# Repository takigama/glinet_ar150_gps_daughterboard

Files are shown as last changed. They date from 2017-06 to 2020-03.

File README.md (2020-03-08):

## Update - 2020, Mar 9

I've been running my little guys for 3 years now. I have two in outdoor cases
being powered over ethernet and they have yet to skip a beat, which is suprising.
As some of you may know, Australia (especially NSW) has been going through
some hard times this summer. First it was an amazing heatwave followed by fire
Then it was floods and intense rain. They endured both. Going up against two
RPI's (both RPI's died in the heat), thats doing pretty well.

I've now added a 2020 firmware release which is based on 19.07.2. This time
i've included all the packages as well and made as many modules as would
compile. If you do need any extra modules, they should now already be available

I've not chaned the firmware to point here for packages however, so you need
to grab them manually.

I also plan on publishing a build guide for the external cases, hopefully
some time soon.

## What be it?

Simple daughter board for the AR150 from GL.inet using the Quectel L80 GPS or
the MTK3339 GPS (there are boards for either)

... and its AWESOME!!!!

... and NOW with added linuxptp AND LEDE support!!!!!

note that it doesnt come configured with much, so most of the daemons included
(ntp, chrony, etc) start up automatically with defaults, you want to change
that

## Why?

meh, why not?

Seriously though, some time ago I used the predessesor of the AR150 and the
uBlox Neo 6m GPS receiver to build a NTP with GPS and PPS for high accuracy
timing. [See here](http://pjrlost.blogspot.com.au/2015/09/ar9331-pps-gps-ntp-awesome.html)
I had to write some code to enable PPS interupt based processing on the AR9331
family (thanks to some code that already supported GPIO's with interrupts)
and was fairly impressed with the results. At home its the prefered clock
source, going up against a RPI1, RPI2 and a Wyse terminal with a serial port
which runs an AMD geode cpu.

Sadly its hard to get the Neo uBlox 6M in an SMD format, but I stumbled onto
the Quectel L80 chip, which is easy to aquire and even smaller than the uBlox. The AR150
has different GPIO pins to the original GL.inet router I had in my previous
project (which is still actually running at home and still out-performing
most other GPS/PPS's i've built).

A number of projects do use the AR9331 as a GPS/PPS/NTP clock, but this was
the first one that I know of that implemented by the gpio interrupt mechanism
(which is more accurate and more efficient).

## How?

Well, first go print a board at oshpark [here](https://oshpark.com/shared_projects/Jt3Wxv2q)
and then go get a Quectel L80 chip (just the chip, no board), a couple of leds
a small mosfet (dont really need it to be honest) and a few resistors and lastly
of course a AR150.

Solder it all together, then sit back and wait for me to port my code on the
blog to the AR150 (only have to change the PPS pin from 13 to 14), or compile
the code yourself and figure that bit out.

Also, when i started this, i was thinking along the lines of the PoE version
of the AR150 (so the AR150 can sit outside in a silicon case with the GPS poking
upward thru the top - i'll post pic's when I build it)

Dont let the SMD scare you, plenty of youtubes up for how to hand solder or heat
gun solder this thing. I use a head gun for everything except the GPS module. I
use a soldering iron for the GPS module.

## BOM

1) 1 x L80 GPS Module or MTK3339 Module
2) 1 x Mosfet (BSS138 or similar) - optional, allows GPS to be power cycled by board
3) 3 x 200ohm 0805 SMD resistors
4) 1 x 2x5 90 degree angled pin header
5) 3 x 0805 leds (colour is up to you)

## GPIO's

So in the project, its using two GPIO's. One is used to turn the GPS itself on
and off. The other is used for the PPS interrupt. GPIO 17 is the power switch
GPIO 14 will be the PPS pin.

## Updates

3/Mar/2018 - There are now two firmwares sitting in the firmware directory. This
update moves my repo from its very-alpha state to something I now consider to be
relatively tested and working fairly stable and as such is now considered beta!

The baords have both beeen tested with fairly good success so far. I would
slightly recommend the L80 GPS over the MTK3339 GPS module as it seems more
sensative and less jittery.

Heres some Pics for you:

L80:
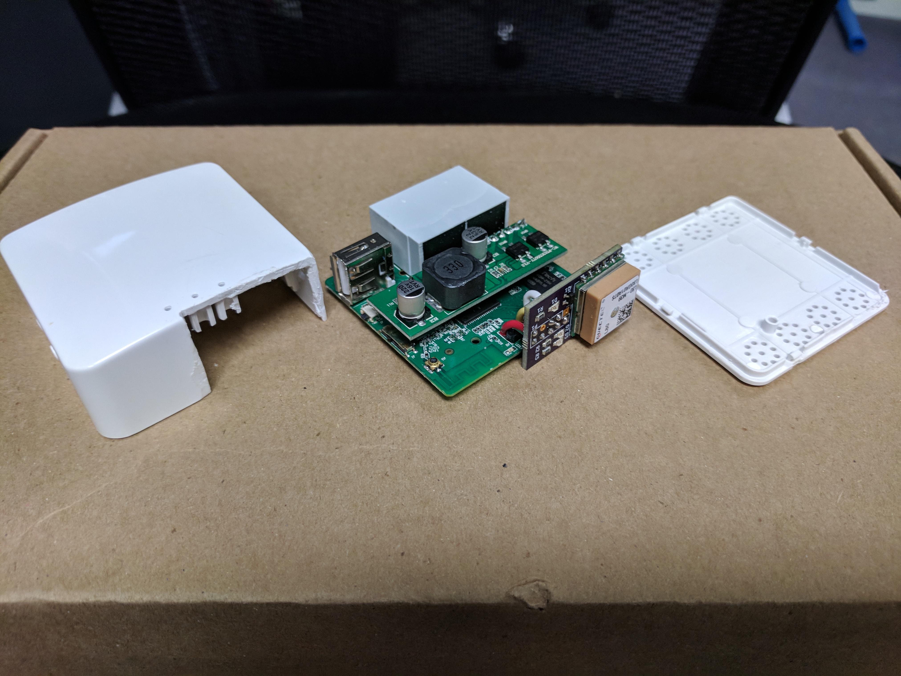
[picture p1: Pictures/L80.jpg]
L80


MTK3339:
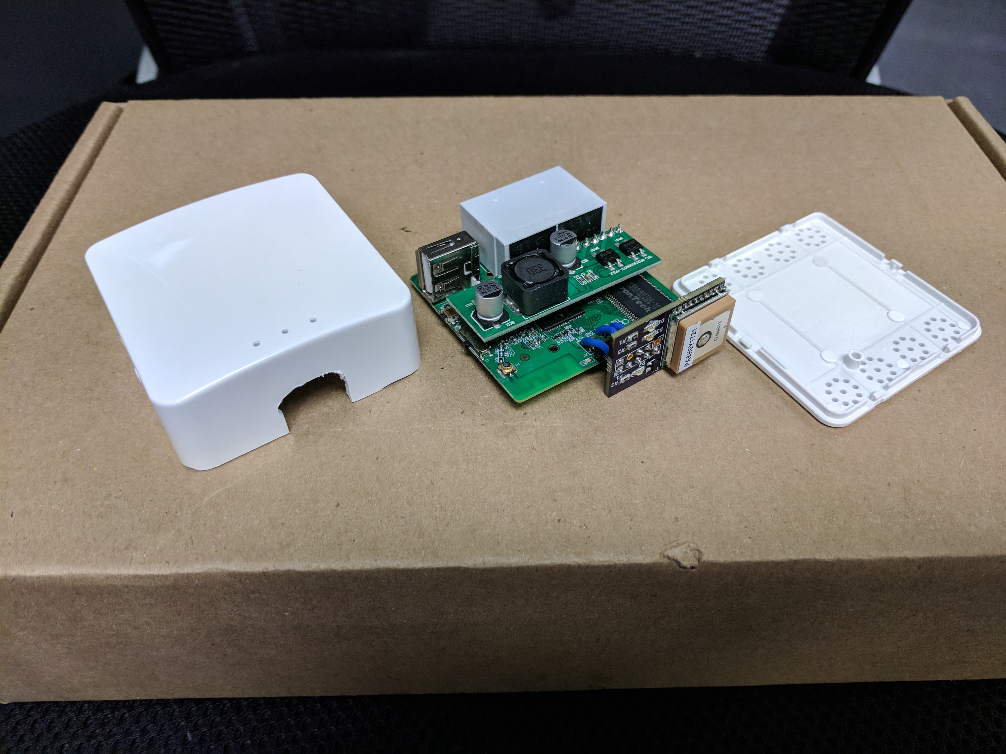
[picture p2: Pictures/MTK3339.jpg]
MTK3339


Theres no alot to distinguish between the two except they have different footprints
on the GPS module

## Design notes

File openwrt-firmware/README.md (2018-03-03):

# New firmwares - 3/Mar/2018

This new firmware is now pretty solid and there are two versions

1. LEDE based (based on lede github master)
2. openwrt based (comes from openwrt's own master git)

## Details

There are quite alof ot packages added, which i'll update shortly
but to install it, upload it to your AR150 (preferably already 
running openwrt) then run from the shell "sysupgrade -v /tmp/my_firmware_file"

Once you've done that, its a good idea to blank it when it comes up
by running "mtd -r erase rootfs_data" (this will reset the router
back to the golden image and reboot it).

On boot it will do a number of things:

1. set WAN interface to DHCP client
2. set wifi SSID to "OpenWRT" and give the wifi a 192.168.254.1 with dhcp server
3. set LAN interface to 192.168.253.1 with a dhcp server
4. enabble gpsd and chrony with two ntp servers on "noselect"
5. disables firewall!!!!
6. disables most every other service
7. disables the serial console

The reason we do all that is to remove as much cpu-consuming tasks from
the router as possible, but it is obviously insecure. If you dont need it
disable the wifi, but I would leave the firewall off, configure a static
IP and shutdown the web interface, and the "LAN" interface. On the PoE
model, the WAN interface is the one that accepts PoE and if your using 
the 3d printed outdoor case (coming soon(tm)), you'll only want a single
ethernet cable coming into the router.

Once its online and you can connect to it (either by plugging LAN into
your network, connecting to the SSID or connecting to the LAN interface)
ssh in and run "chronyc sources", it should start syncing. You can also
make sure gpsd is running correctly with cgps (you should see a 9600 baud
rate on the serial line)

One problem - for some reason after a sysupgrade or mtd erase step the wifi
does not come back online unless the router is rebooted again. So after
upgrading and resetting, make sure you reboot if you need wireless!

I'll make the firmwares available soon on githuba

If your not sure which firmware you installed, have a look in /etc/taki
and there will be a 0 byte file that it is either "lede" or "operwrt".

## PTP

This version has full ptp support, and starts the ptp daemon on startup
with the following parameters:

1. Software clock
2. Binds to eth0 and eth1
3. E2E delay
4. Pri1 and 2 at 128
5. Domain ID 0

## NTPD instead of Chrony.

My firmware defaults to starting up chrony. If you wish to use ntpd instead
just disable the chrony startup and enable the ntp one. Then configure
the ntpd.

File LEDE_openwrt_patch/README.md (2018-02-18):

# LEDE Patch for AR150 support

quick and nasty:

1. this is a hack
2. this IS a hack
3. hard codes the pps-gpio module to the GL-AR150
4. includes the configuration for building lede
5. follow https://openwrt.org/docs/guide-developer/quickstart-build-images for building lede
6. copy the lede patch 940-lede-patch-for-ar150-pps-gpio.patch to target/linux/ar71xx/patches-4.9/

Build it all!

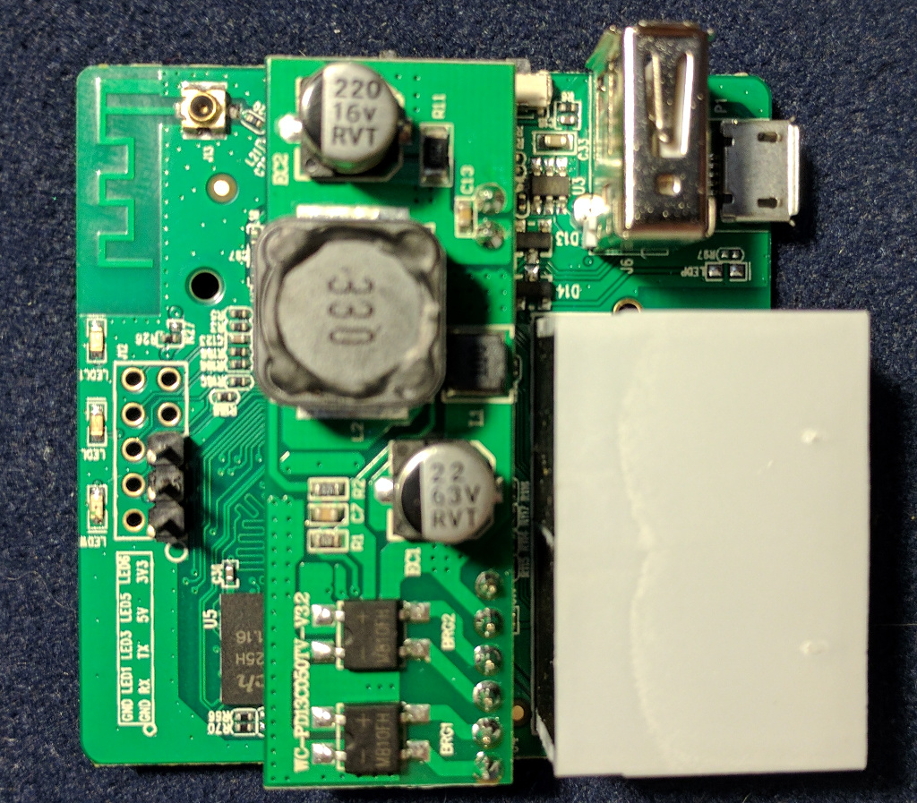
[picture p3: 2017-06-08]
GL150_pinout_change/IMG_20170608_214517_ws.jpg

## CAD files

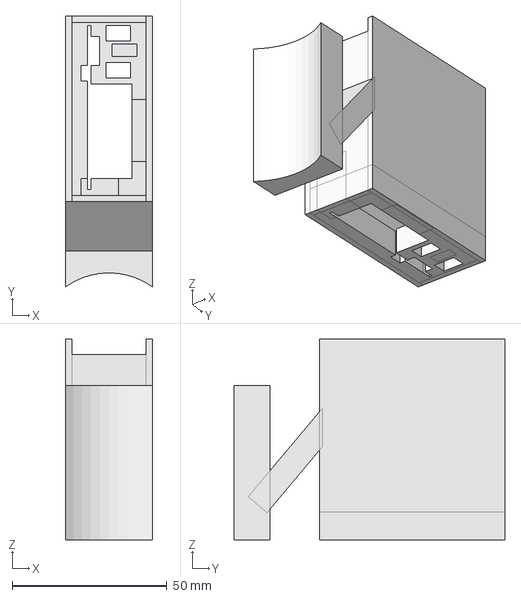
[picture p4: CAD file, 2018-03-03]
3D Printed Outdoor Case/maincase.fcstd
28.0 x 87.5 x 65.0 mm

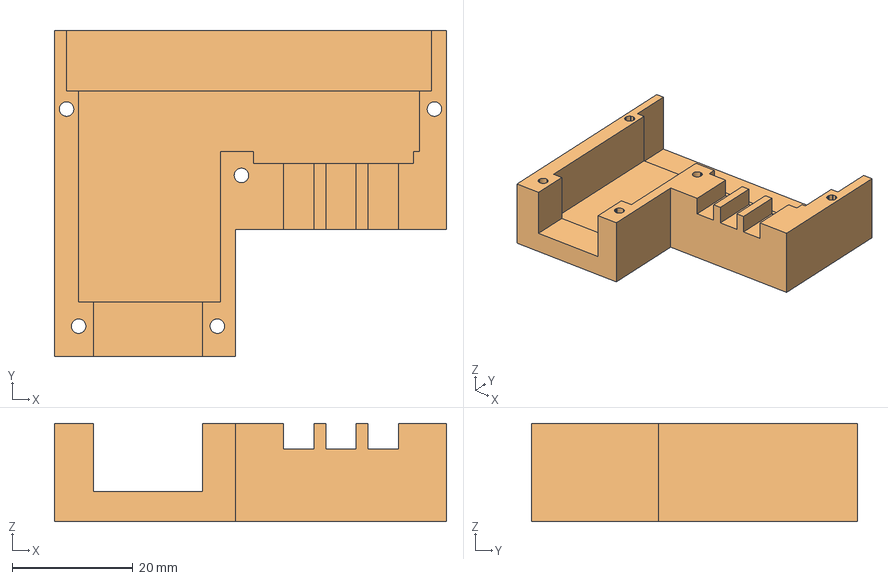
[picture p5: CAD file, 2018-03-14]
3D Printed Outdoor Case/cablein.fcstd
65.0 x 54.0 x 16.2 mm
Cut (Meshed)

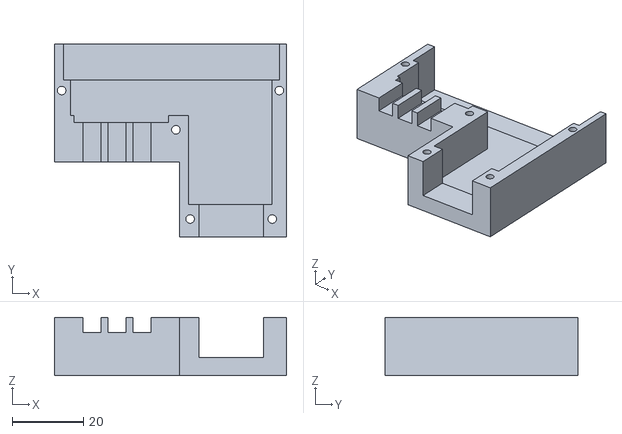
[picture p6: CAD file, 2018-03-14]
3D Printed Outdoor Case/cablein (mirrored).stl
65.0 x 54.0 x 16.2

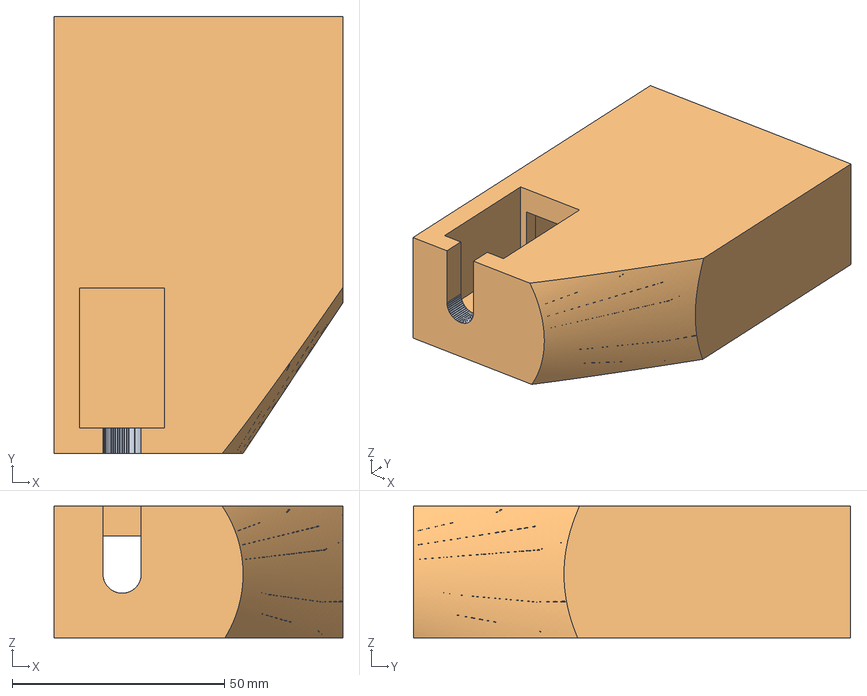
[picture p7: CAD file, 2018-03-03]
3D Printed Outdoor Case/ntpcase.fcstd
68.0 x 103.0 x 31.0 mm
Cut002 (Meshed)

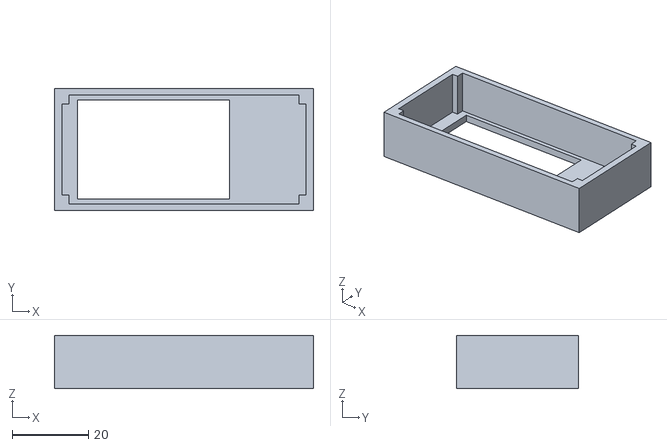
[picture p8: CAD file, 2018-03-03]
3D Printed Outdoor Case/captotp.stl
68.0 x 32.0 x 14.0

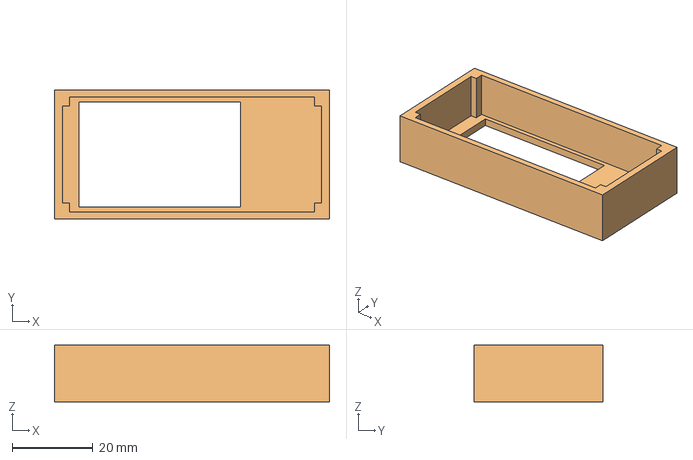
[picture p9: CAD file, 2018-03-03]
3D Printed Outdoor Case/cap_top.fcstd
68.0 x 32.0 x 14.0 mm
Cut (Meshed)

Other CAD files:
3D Printed Outdoor Case/cablein.stl
3D Printed Outdoor Case/maincase.stl
3D Printed Outdoor Case/ntpcase.stl

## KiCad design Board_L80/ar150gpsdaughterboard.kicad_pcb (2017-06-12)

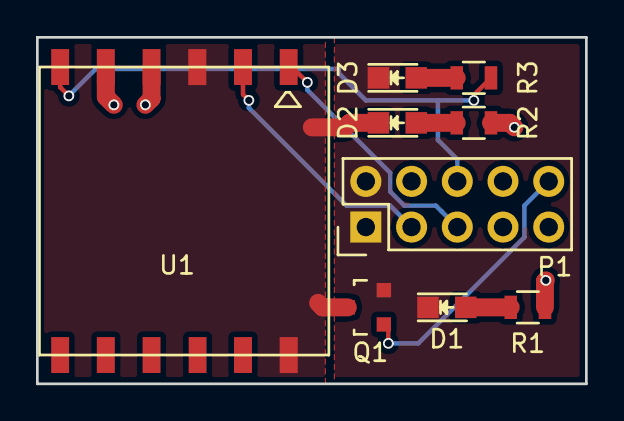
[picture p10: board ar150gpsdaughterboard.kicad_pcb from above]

Board: 2 copper layers, 30.5 x 19.2 mm, 9 parts (0 on the bottom side), 10 nets.

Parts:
D1, D2, D3: LED; LED_0805
P1: CONN_02X05; Pin_Header_Straight_2x05
Q1: BSS138; SOT-23
R1, R2, R3: 300; R_0805
U1: QUECTEL-L80

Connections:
+3V3: P1.9, R1.1, R2.1, U1.4, U1.5
GND: D1.1, D3.1, P1.1, P1.2, Q1.2
GP_14: P1.6, R3.1, U1.6
GP_17: P1.10, Q1.1
GP_GND: D2.1, Q1.3, U1.3, U1.12
unnamed: D1.2, R1.2
unnamed: D2.2, R2.2
unnamed: D3.2, R3.2
RX: P1.3, U1.2
TX: P1.5, U1.1

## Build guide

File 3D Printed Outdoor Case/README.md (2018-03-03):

# 3d Printed Outdoor Case

Its kind of a work in progress

How it comes together:

1. print maincase, cablein (and mirrored) and top
2. get a peice of silicon for the top
3. in cablein, theres a place to glue in a piece of mesh
4. rap some silicon around the cable going into cable in for water-proofedness
5. waterproof the rest
6. glue it together (cablein has holes for 1.75m filimant to hold it together).
7. .....
8. PROFIT!!!

if you cant figure it out from that, then you can try but when i complete this work
i'll give some instructions with photos and a better explanation.

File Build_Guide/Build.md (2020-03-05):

# Quick Run Through

## And then there was light

1. git clone https://git.openwrt.org/openwrt/openwrt.git
2. cd openwrt
3. git checkout v19.07.2
4. ./scripts/feeds update -a
5. ./scripts/feeds install -a
6. copy config.built to ./.config
7. copy 940-lede-patch-for-ar150-pps-gpio.patch to target/linux/ar71xx/patches-4.14/
8. make menuconfig (adjust as you need)
9. make
10. Cross fingers
11. firmware should now be in bin/targets/ar71xx/generic/

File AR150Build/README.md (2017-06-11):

## Details for building openwrt for this project...

The quick and dirty:
git clone https://github.com/openwrt/openwrt.git
git checkout d95f4c6ca377edcdf8c827a50b5e67e12313f9f6
git reset --hard # just incase

copy the 971 patch in this dir to target/linux/ar71xx/patches-4.1/ in your openwrt directory
copy the config in this directory to the root of your openwrt directory

Hope that it all builds. Theres one file that isnt downloaded during the build called
DPO_MT7601U_LinuxSTA_3.0.0.4_20130913.tar.bz2 which can be found via google. Download
that and it goes into your openwrt under a directory called dl/

upgrade your ar150 with the firmware you finially get out of it.

Or just upload the firmware in the openwrt-firmware directory.

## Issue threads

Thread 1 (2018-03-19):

Mounting ext4 USB

andersen73, 2018-03-19:
Loving the PPS on my AR150! Sadly, I'm not able to mount any USB drive (vfat, ext4, ntfs, etc...). Is there a reason why I'm not able to mount any USB flash drives? Are you seeing the same thing on your end? I need to be able to capture tcpdump .caps locally. Any help is appreciated. If you need any information from my end, please let me know. Thanks

takigama, 2018-07-02:
Probably my firmware (sorry just noticed the issue, must of missed the email), i'll compile a new one with the needed options added.

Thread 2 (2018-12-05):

Some Qs

Strykar, 2018-12-05:
1. What are your thoughts on using this [Uputronics breakout GPS board](https://store.uputronics.com/index.php?route=product/product&path=60_64&product_id=84) with the AR-150? I have an [external antenna](https://store.uputronics.com/index.php?route=product/product&path=60_65&product_id=74).
2. Why install PTP on the AR-150, iirc the AR9331 SoC NIC's don't support hardware time-stamping?
3. Have you tried https://github.com/mlichvar/pps-gpio-poll with your daughterboard? _Unlike the pps-gpio module (which is included in the Linux tree) it doesn’t use interrupts. It uses a high-resolution timer and waits for the GPIO value to change in a busy loop instead._
4. Could you post some performance numbers of the Quectel and MTK GPS?

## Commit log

2017-05-10 GL.inet AR150 GPS Daughter board Project
    [_saved_ar150gpsdaughterboard.sch, ar150gpsdaughterboard.dsn, ar150gpsdaughterboard.kicad_pcb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]
2017-06-08 new pinout
    [_saved_ar150gpsdaughterboard.sch, ar150gpsdaughterboard.sch]
2017-06-08 Updated board layout - new L80 footprint, better location of pins
    [ar150gpsdaughterboard.kicad_pcb]
2017-06-08 updated oshpark link in readme
    [ar150gpsdaughterboard.kicad_pcb]
2017-06-09 updated pinout of the ar150 pin header
    [ar150gpsdaughterboard.kicad_pcb, ar150gpsdaughterboard.sch]
2017-06-11 new board with a pps line indicator
    [ar150gpsdaughterboard.kicad_pcb, ar150gpsdaughterboard.sch]
2017-06-11 reloaction for an mtk based board
    [ar150gpsdaughterboard.dsn, ar150gpsdaughterboard.kicad_pcb, ar150gpsdaughterboard.sch]
2017-06-11 complete MTK board
    [ar150gpsdaughterboard.dsn, ar150gpsdaughterboard.kicad_pcb, ar150gpsdaughterboard.sch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]
2017-06-12 updated baord for MTK3339 - should sit more correclty now
    [mtk3339board.kicad_pcb]
2017-06-12 updated baord for L80 - should sit more correclty now
    [ar150gpsdaughterboard.kicad_pcb]
2017-11-22 Added photo's of built boards
2018-02-18 added complete hack to support lede, proper linuxptp support
2018-02-18 new lede firmwre - extra packages
2018-03-03 added 3d printed case
    [cablein (mirrored).stl, cablein.fcstd, cablein.stl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]
2018-03-14 Changed the cablein gland so it can accomodate a rj45 withtot having to seal it in
    [cablein (mirrored).stl, cablein.fcstd, cablein.stl]
2020-03-05 added current config
